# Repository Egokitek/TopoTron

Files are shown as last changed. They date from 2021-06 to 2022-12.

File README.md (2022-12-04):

# TopoTron

## Un display volumétrico de baja resolución 

### Concepto

**TopoTron** es un display volumétrico que utiliza LEDs direccionables **2812** para crear una matriz tridimensional. En este proyecto se exploran las posibilidades y capacidades que un dispositivo de este tipo ofrece para crear no solo topografías sino efectos visuales, animaciones etc.

Se asemeja en concepto a los conocidos **cubos LED**, pero en este caso el factor de forma es diferente, es un prisma de poca altura y bastante base. De este modo se pueden mostrar topografías mas fácilmente. También se presta atención a los difusores de luz de los LED . En un cubo LED normalmente no se emplean por lo que vemos una matriz de puntos luminosos que pueden crear efectos visuales pero no dan una buena sensación de volumen. En Topotron los difusores buscan un compromiso entre recrear un volumen y no entorpecer visualmente los LED que se encienden al frente con los que se encienden por detrás. Asi que el tipo de material del difusor, su tamaño y forma, y la distancia entre los mismos influyen en el efecto a conseguir.

En esta imagen de concepto vemos el objetivo ideal. Se ha realizado mediante el programa opensource **MagicaVoxel.**

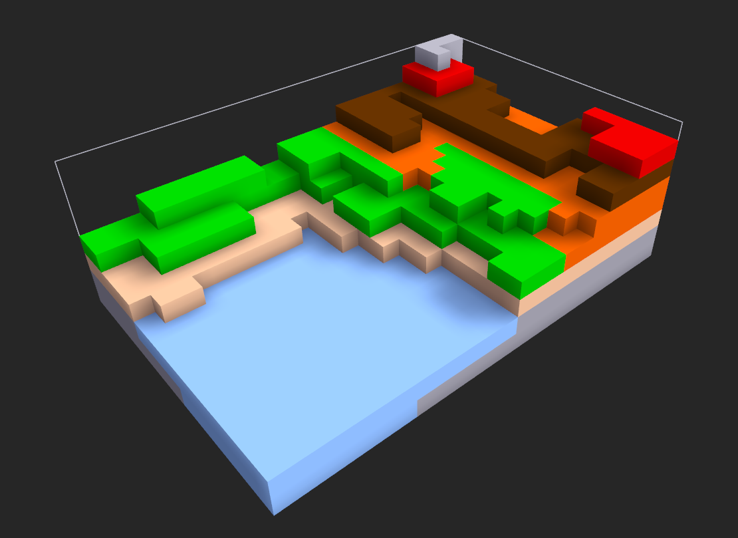
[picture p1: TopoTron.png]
TopoTron


### Características de los modelos y versiones:

- **Prototipo** desarrollado en verano 2021. **5x7x7 vóxeles** (245 LED totales). Construido sobre protoboards para facilitar el ensamblado y pruebas. Modelo usado como muestra en la campaña de crowdfunding. ESP8266 y firmware FASTLED modificado.

- **Versión 1 o mediana**. Desarrollado en primavera de 2022. **8x5x7 vóxeles** (280 LED totales). Completamente impreso en 3D con cableado y ensamblado interno. Procesador ESP8266 y firmware FastLED modificado.

- **Versión 2 o pequeña**. Desarrollado en verano de 2022. **5x5x10 vóxeles** (250 LED totales). Completamente impreso en 3D con cableado y ensamblado interno. Procesador ESP8266 y firmware WLED modificado. Versión modular que se puede ensamblar en unidades mayores.

La versión que se entregará como recompensa es la 2, que es por el momento la versión final y puede servir para crear modelos de tamaños diversos. Los vemos a continuación:

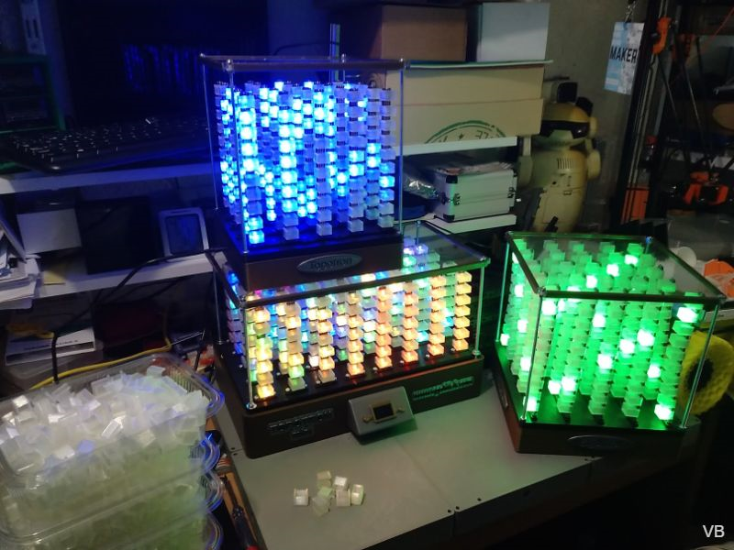
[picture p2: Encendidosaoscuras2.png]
Encendidos a oscuras


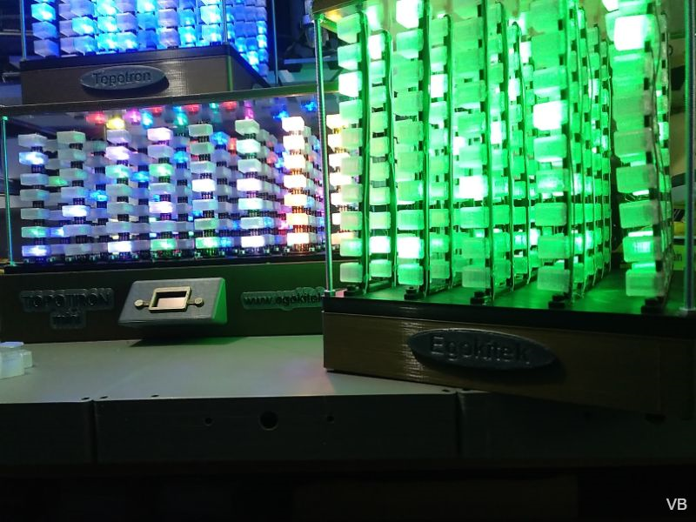
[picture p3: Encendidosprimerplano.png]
Encendidos primer plano


### Modelo grande (objetivo del proyecto): 

- **Versión L** en construcción, finalización en diciembre de 2022. Matriz mas grande con 15x10x10 vóxeles (1500 LED totales) o similar. Formada por 6 modelos V2 unidos entre si. Procesador ESP32 y firmware WLED modificado.

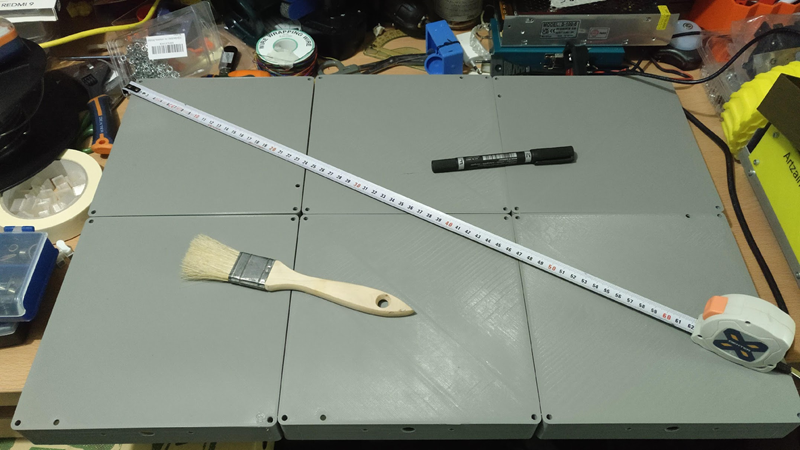
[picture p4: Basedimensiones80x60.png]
Modelo grande en construcción


### Lista de materiales (BOM):

El enlace está **[aquí](BOM.xlsx)** (en construcción):

### Crowdfunding y cofinanciadores:

Este proyecto se inicio como concepto y se prototipó en el marco del concurso internacional **Hackaday Prize** realizado en 2021. El enlace a ese proyecto (en inglés) está **[aquí](https://hackaday.io/project/180204-topotron).**

Se presentó a concurso y no quedó seleccionado, pero la idea me gustó y quise seguir trabajando con ella, con el fin de construir una unidad mas grande y ver así las posibilidades que ofrecía. Por ello me presenté a crowdfunding con la **Fundación Goteo** y a final de 2021 conseguí los fondos necesarios. 

Asi que este proyecto no hubiera sido posible sin el apoyo de las personas y colectivos que lo han cofinanciado. 

La ficha del proyecto en la **Plataforma Goteo** la tienes **[aquí](https://www.goteo.org/project/topotron).**

La lista de personas y colectivos que han contribuido a la financiación la tienes **[aquí](Cofinanciadores.md).**

### Futuro del proyecto:

En septiembre de 2022 he entrado a la empresa **Camp Tecnológico** dedicada entre otras cosas a la formación y el ocio tecnológico. En ella ampliaremos el catálogo de productos y servicios ya existente, al que se añadirá este proyecto.

Es un proyecto opensource con licencia GPL3.0, asi que eres libre de utilizarlo como quieras. Pero le seguiré dando continuidad desde el seno de la empresa en la que estoy actualmente.

## Creditos

**TopoTron** es un concepto desarrollado por **Victor Barahona** en **[Egokitek](https://www.egokitek.com/)**.

Se ha inspirado en los **cubos LED** y otros conceptos de **display volumétricos**.

En este proyecto estoy utilizando las librerías **FASTLED y WLED** con modificaciones.

## Licencia

**GPL3.0**

## Video demostrativo y mas imágenes:

Tienes mas imágenes en la carpeta de [**Galería.**](/Galería/README.md)

En este video teneis una muestra del desarrollo. Forma parte de una lista con varios videos mas. Os invito a ver el resto de contenidos. **[Topotron: desarrollo del proyecto](https://youtu.be/e-akGpGEZ80)**.

Renderizados hechos con **MagicaVoxel**

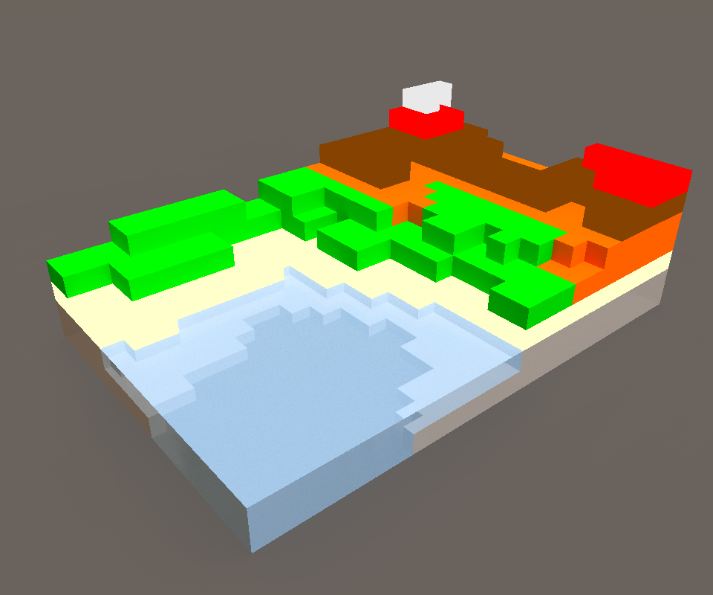
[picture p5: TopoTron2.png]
TopoTron2


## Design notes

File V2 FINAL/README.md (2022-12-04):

## Versión 2

### **Versión 2** (final) terminada en verano de 2022. 
 
Matriz con 5x5x10 vóxeles (250 LED totales). Completamente impresa en 3D con cableado y ensamblado interno. Procesador ESP8266 y firmware WLED modificado. Versión modular que se puede ensamblar en unidades mayores.

**Este es el aspecto del renderizado previo (realizado en Fusion360):**

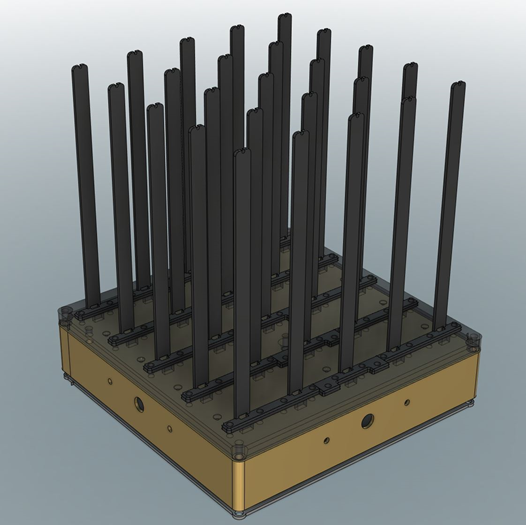
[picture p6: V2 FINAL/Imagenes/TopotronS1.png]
Renderizado en Fusion 360


**La unidad terminada se ve así.** En este caso está dada la vuelta, es algo posible debido a la placa superior protectora en metacrilato unida mediante barras roscadas de métrica 4.

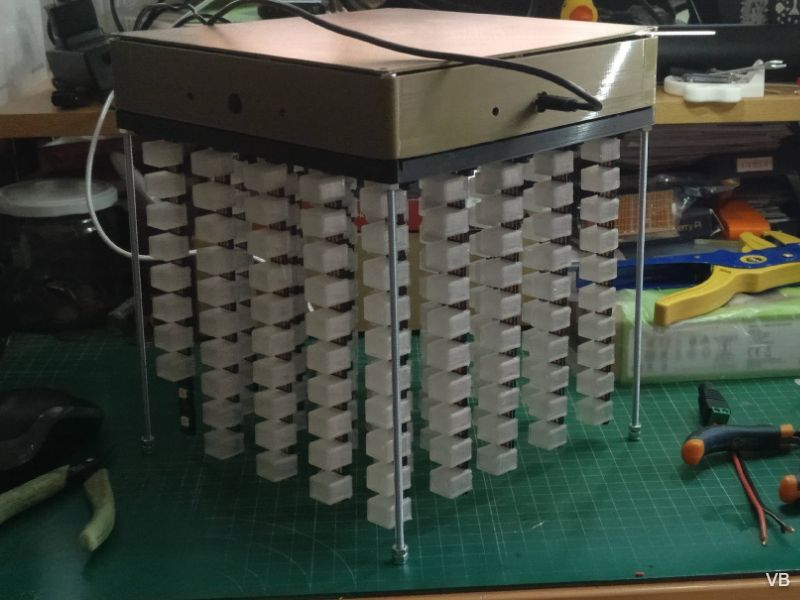
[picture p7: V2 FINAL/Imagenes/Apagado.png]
Topotron apagado


**Encendida se ve de esta manera:**

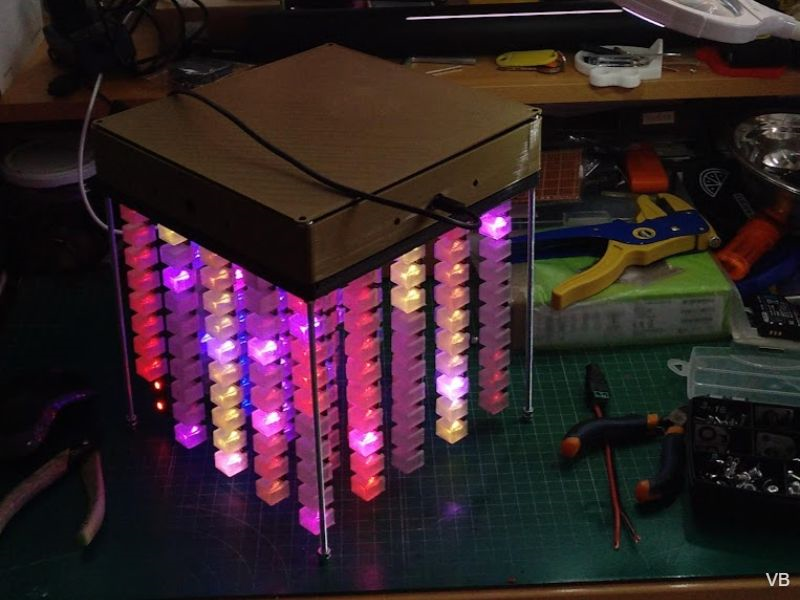
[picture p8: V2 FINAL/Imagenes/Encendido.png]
Topotron encendido


**Curiosamente basta con alimentar con una fuente USB de móviles al microcontrolador.** Este puede suministrar suficiente corriente para que los LED funcionen tal y como se ve en las fotos. Esto se debe a que el microcontrolador ESP8266 tiene una pataVin que puede servir de salida de la tension entrante por su puerto miniusb. Se limita por software la corriente máxima de salida a unos 500mA. Hay quien dice que se puede sacar hasta 1A o 1000mA) pero por precaución lo dejo en 500. No me han dado ningun problema los diferentes modelos que he construido hasta ahora para las recompensas.

### ¿Cómo se construye?

- Imprimimos 5 piezas de "Barra LED 5x10" , preferentemente en color negro, y sobre ellas pegamos tiras LED con una longitud de 10 LED. Antes de pegarlas les soldamos previamente un cable rojo para 5V, otro negro para GND y otro de cualquier color para Din (data input). todos estos cables han de tener una longitud de unos 3cm en 3 de las piezas. En una el de 5V será mas largo, de unos 8cm. Y en otra el GND tendrá 8cm. Esto se debe a las necesidades de conexionado posterior. Despues de soldar estos cables podemos pasarlos por un agujero en el soporte de "Barra LED 5x10", hay uno por cada tira. Y despues podemos pegarlas.

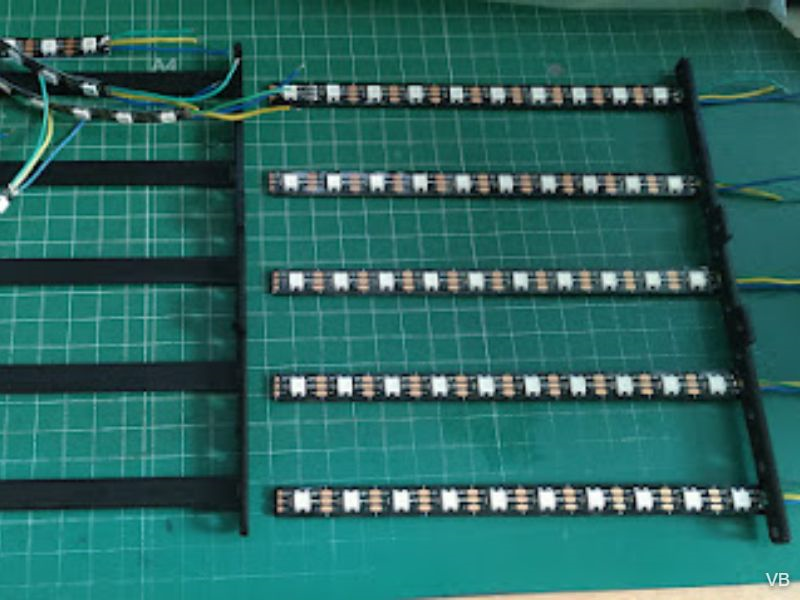
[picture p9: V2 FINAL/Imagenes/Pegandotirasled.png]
Pegando tiras LED


- Despues soldamos en la parte superior de cada tira, en su pin Dout, un cable largo de unos 20cm. En mi caso he empleado hilos de un antiguo bus IDE de ordenador, ya que son finos, flexibles y perfectamente válidos para esta tarea. Pero vale cualquier otro. Es conveniente que sea oscuro para que no destaque mucho sobre la pieza que es negra, ya que irá pegado en su parte posterior.

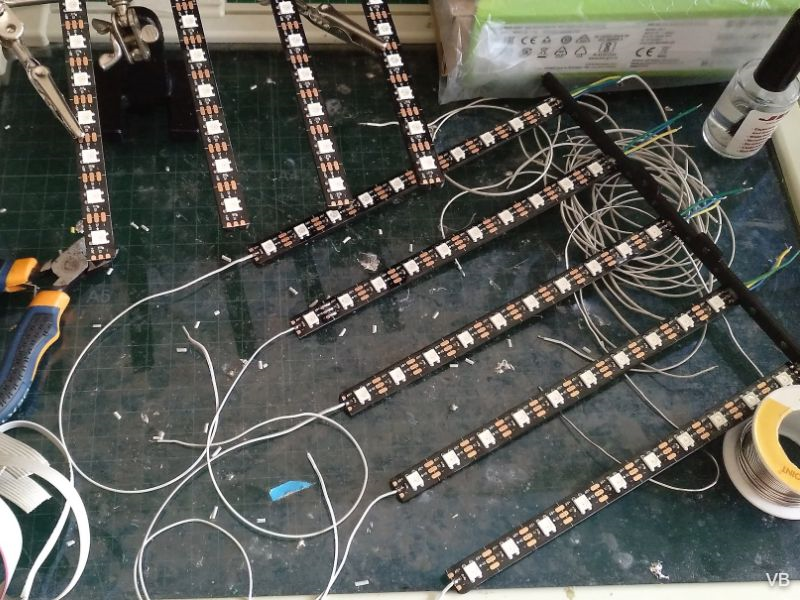
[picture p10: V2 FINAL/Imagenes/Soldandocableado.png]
Soldando cableado


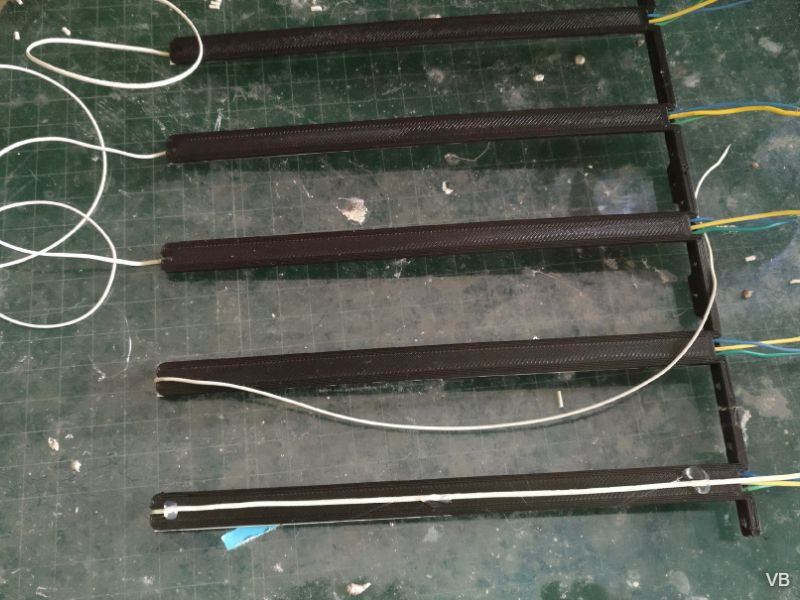
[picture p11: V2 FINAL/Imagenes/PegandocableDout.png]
Pegando cable Dout


- Después podemos pegar una a una todos los difusores sobre cada uno de los LED. Son 250 piezas de "celda QUAD v3". Las imprimimos en lotes de 25, 50 o como podamos, en PLA transparente o resina. En el caso de PLA con 3 perímetros y top/bottom de 3. Para pegarlas  el cianocrilato es una opción pero a mi me ha dado bastantes problemas. Recomiendo cola termofusible para esta tarea:

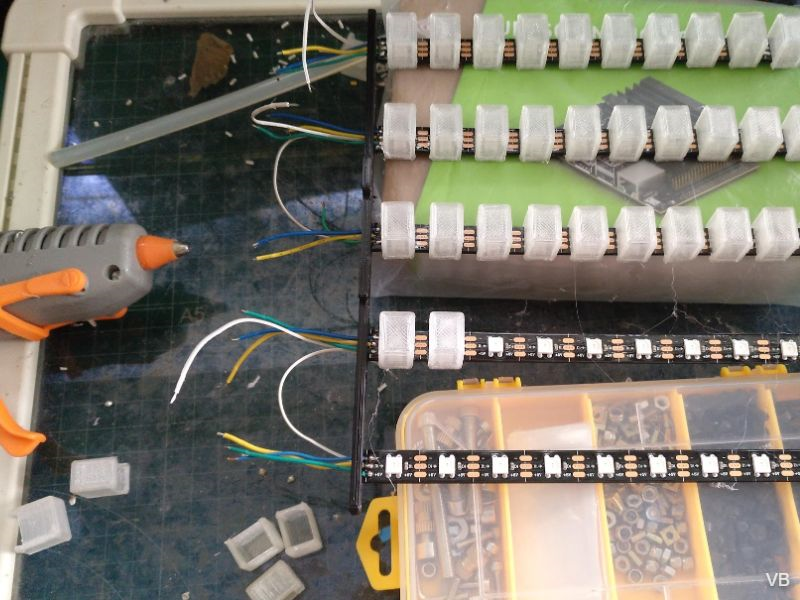
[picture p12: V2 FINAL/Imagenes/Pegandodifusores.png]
Pegando difusores


- Después de terminar las 5 piezas soporte de LED podemos unirlas a la pieza "Base tiras LED 5x5" (de esta sólo se imprime una). Los que tienen los colores rojo y negro de la misma longitud (sobre 3cm) están en las 3 posiciones centrales de la base. Mientras que los que tienen cable rojo (o negro) de unos 8cm se colocan en los extremos de la base. Primero debemos pasar el cableado (4 hilos por cada barra LED) a través del agujero correspondiente en la base, y cuando pasamos todos los hilos de las 5 barras de esa pieza se puede unir a la base con dos tornillos m3x10 a ambos lados, con la tuerca por la parte inferior. Apretamos bien y de ese modo todas las barras LED quedarán paralelas y verticales. Bien alineadas. Tenemos mas agujeros pasantes por si queremos poner mas tornillos m3x10 y reforzar la unión. Preferentemente usamos tornillos negros.

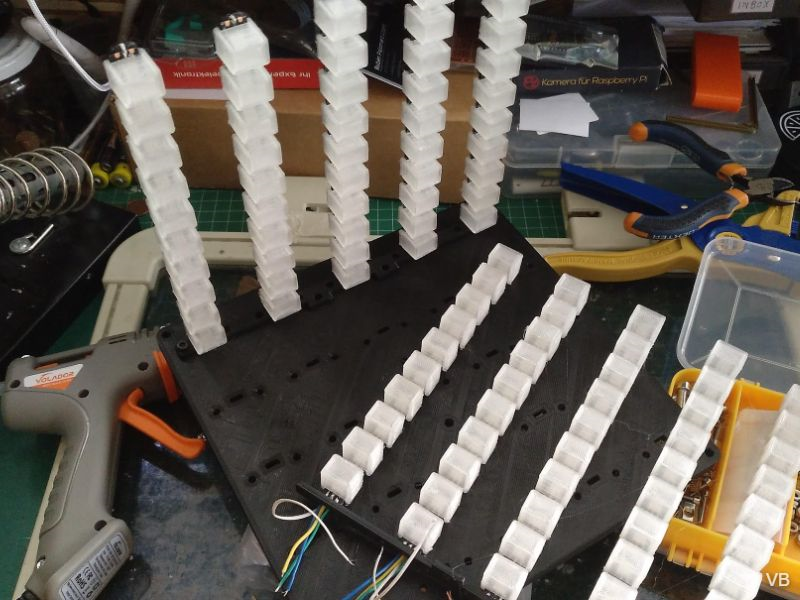
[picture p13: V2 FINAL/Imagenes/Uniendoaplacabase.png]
Uniendo a placa base


- Tras unir todas las piezas, si damos la vuelta al conjunto lo veremos de esta manera, con todos los cables pendientes de soldar. Atención, en la foto no se ven de color negro y rojo, solo es una recomendación para no confundirse, pero pueden emplearse otros colores como en este caso.

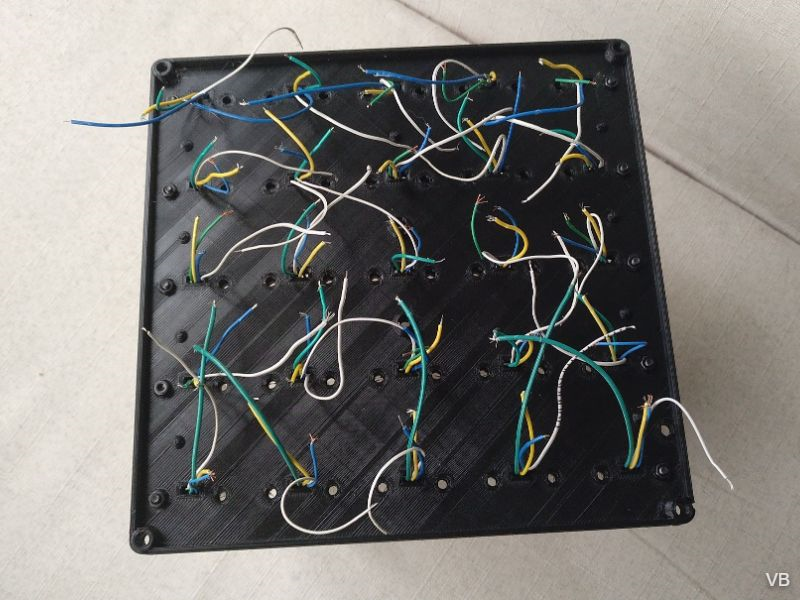
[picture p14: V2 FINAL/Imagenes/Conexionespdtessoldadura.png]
Conexiones pendientes de soldadura


- Cortamos 4 alambres de acero de aprox 1mm de diametro y 19cm de largo. Los pegamos con cinta de carrocero a la base, sobre unos pequeños promontorios en la pieza (hay 3 por cada alambre). Esto permitira hacer las soldaduras reduciendo el contacto directo con la pieza de PLA, que se puede dañar. Estos alambres serán 5V, GND, 5V, GND, en ese orden, de tal modo que todas las barras tendrán cerca alambres a los que ser soldados.

- Soldamos por tanto los cables rojos y negros a sus correspondiente alambres de 5V y GND. Los que tienen los colores rojo y negro de la misma longitud (sobre 3cm) están en las 3 posiciones centrales de la base. Mientras que los que tienen cable rojo (o negro) de unos 8cm se colocan en los extremos de la base, de tal forma que el cable largo va al alambre correspondiente que le queda a mayor distancia. Cuando terminemos de soldar todo podemos pegar los alambres con cola termofusible a los promontorios y retiramos la cinta de carrocero.

- Una vez de hecho lo anterior debemos unir cada cable Dout de una barra al cable Din de la siguiente, para que esten conectados en serie. El primer Din está libre porque es el que conectaremos al microcontrolador. El ultimo quedará sin conectar. Si miramos el conjunto de frente desde la parte superior empezaremos por la fila del fondo empezando a la izquierda. El primer Din a la izquierda es el que val controlador. De ahi conectamos su Dout a la Din de la siguiente columna LED, y asi sucesivamente a la derecha. Cuando llegamos a la ultima barra conectamos a la ultima en la derecha en la fila precedente, que es la que le queda contigua. Y en esa fila precedente conectamos de derecha a izquierda. La siguiente fila (la central) vamos de izquierda a derecha), la siguiente a izquierdas y por fin la quinta y ultima fila, la que está al frente a derechas. Esto es un poco lioso, lo ideal sería una foto o gráfico pero he sacado varias y no se aprecia bien. Adjunto una foto por si resulta aclaratorio. **IMPORTANTE: Poner un trozo de termoretractil a cada unión de datos para evitar cortocircuitos o comportamientos indeseados.**

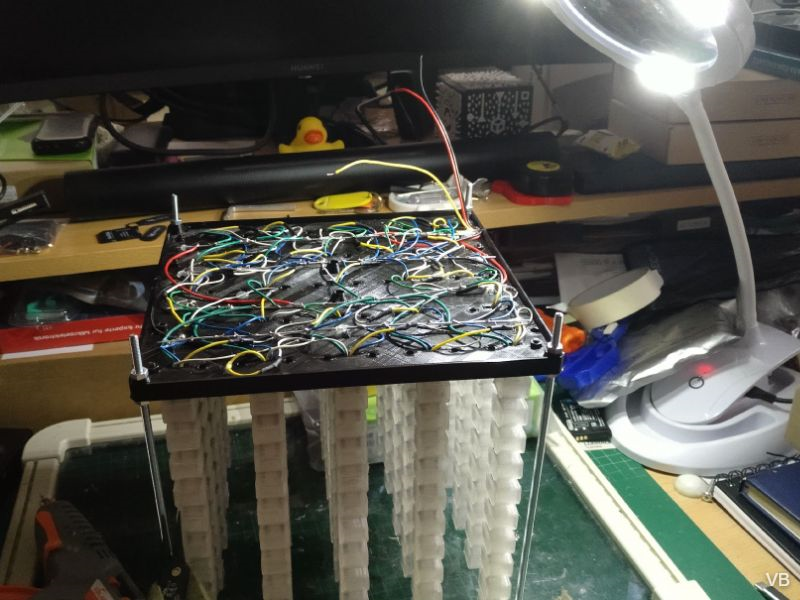
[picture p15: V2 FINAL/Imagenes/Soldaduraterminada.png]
Soldadura terminada


- Conectamos los dos alambres de 5V y los dos de GND entre si con un trozo de cable de suficiente sección.

- Conectamos un cable rojo a 5V y otro a GND, de suficiente sección, y de unos 15cm de longitud. De tal forma que esten alineados para poder salir por un agujero pasante a través de la pieza "base ppal" (ver mas adelante).

- **Conectamos el cable de Din de la primera barra LED a una resistencia de unos 470ohm** y despues a un cable de unos 15cm, este conectará al microcontrolador. Puede ponerse la resistencia al otro extremo, en el lado del MC. Este cable pasará también por el agujero pasante con los dos de 5V y GND.

- Hacemos una prueba de encendido (ver [**aquí**](/SW%20y%20configuración/README.md)) para asegurarnos de que todo funciona. Si es así, adelante al siguiente paso. Si no, toca revisar y reparar la/s soldaduras defectuosas, que es habitualmente la fuente de problemas.

- Si todo está bien podemos acomodar los cables para que abulten lo menos posible, incluso pegando en algunos puntos con cola termofusible. Quedará como en la foto.

- El controlador se coloca en la pieza "base ppal", sobre un espacio habilitado para ello, de tal forma que puerto micro usb quede apuntando el exterior por un egujero a medida. Le colocamos tornillos de m3x10 con tuerca a los agujeros al efecto en "base ppal". Puede que no entren los 4, pero basta con que entren dos en diagonal para que quede firmemente sujeto. El cableado se ha probado previamente en la prueba de encendido.

- Colocamos la "base de tiras led" en la pieza "base ppal" . Veremos 4 agujeros en las esquinas, son de métrica 4. Pasaremos 4 varillas roscadas de M4 y unos 25cm de largo c/u, a traves de la base de tiras led y la base ppal. Fijaremos ambas piezas con tuerca y contratuerca, de tal forma que por abajo sobresalga de la base ppal unos 2-3mm y queden base ppal y "base de tiras led" unidas. Debe haber una holgura de 1mm entre ambas. Es normal porque los promontorios de "base tiras led" están diseñado de esa manera. Es para que haya suficiente espacio para el cableado que se ha soldado.

- Conectamos Vin, GND y Din al cableado que llega desde la "base de tiras led" y fijamos este cableado para que no se mueva.

- Colocamos la pieza "tapa inferior", encaja a medida en las 4 varillas m4 y podemos unirla a la base. Cerramos con tuerca o mejor aun con tuerca autoblocante (nyloc).

- Pegamos con termofusible "Rotulo Topotron V2" en el frontal, "Rótulo Egokitek V2" en el lateral derecho y "Tapa decorativa" en la parte trasera. El lateral izquierdo se deja libre ya que es el punto de acceso al puerto microusb del microcontrolador.

- Cortamos una pieza de metacrilato de 20x20cm y la presentamos sobre las varillas roscadas. Marcamos los puntos y taladramos. La insertamos, de tal manera que tenemos tuerca y contratuerca para sujetarla. La tuerca superior puede ser una nyloc para evitar que se afloje con el tiempo.

- Por último pegamos en las aristas la pieza "arista 16cm", debemos sacar 4 copias. Estos es opcional pero sirve para cubrir la arista que puede ser afilada o tener un corte irregular. En la foto podemos ver el aspecto final que tiene. 
 
  ### A partir de ahora toca usar el equipo. 
  
  Para ello ve [**aquí**](/SW%20y%20configuración/README.md)

**Si quieres ver fotos del equipo encendido las tienes en la**  [**Galería:**](/Galería)

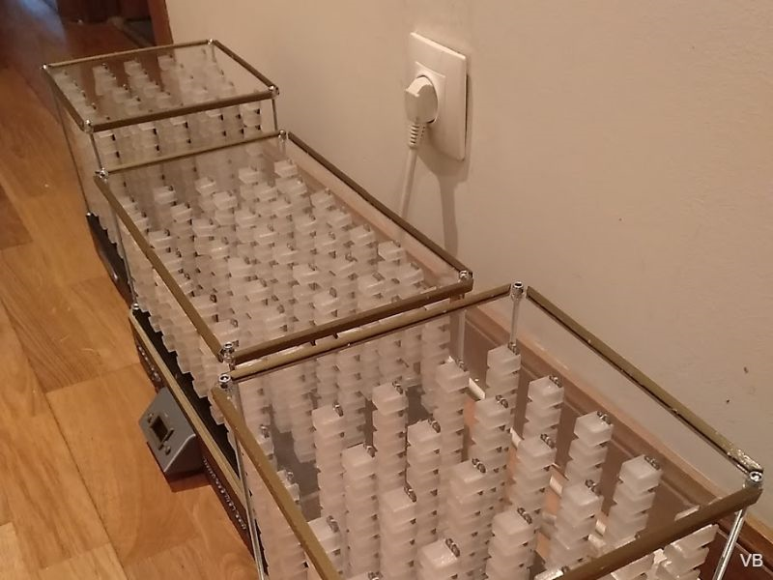
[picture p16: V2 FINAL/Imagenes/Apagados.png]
Apagados


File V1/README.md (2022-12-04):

## Versión 1 (M)

#### **Versión M** finalizada en primavera 2022. 
 
Matriz con 8x5x7 vóxeles (280 LED totales). Completamente impreso en 3D con cableado y ensamblado interno. Procesador ESP8266 y firmware FastLED modificado.

Inicialmente quería incluir un interfaz básico con display oled de 0,96 pulgadas y dos pulsadores. Llegó a estar operativo, pero al tiempo que lo terminaba encontré un proyecto que permitía manejar por wifi , se llama **WLED** y es el que finalmente he desplegado en todos los equipos. Reúne casi todos los requisitos que buscaba y con un excelente interfaz que puedes manejar desde movil, tableta u ordenador. 

**Este equipo** tiene un ancho de unos 32cm, lo que **requiere una impresora grande**. En mi caso utilicé una **Artillery X1**. El tema del tamaño me llevó a rediseñar el proyecto para que fuera modular y mas facil de imprimir. Por eso mismo no me detengo en su proceso constructivo, sino que adjunto algunas fotos. Si quieres hacer uno te recomiendo que vayas directamente a la versión dos que tienes [**aquí.**](/V2%20FINAL/README.md)

- En primer lugar, un renderizado hecho con **Fusion360:**
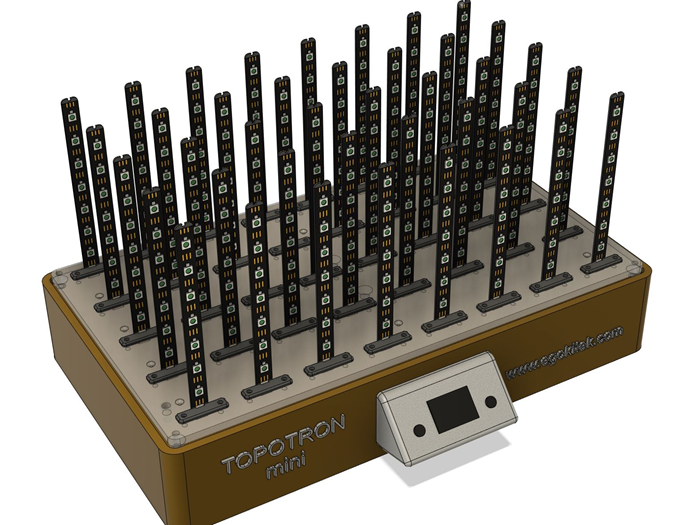
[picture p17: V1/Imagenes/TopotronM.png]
Topotron M renderizado


- La base se imprimió en color dorado ya que quería dar a este equipo un toque **steampunk:**
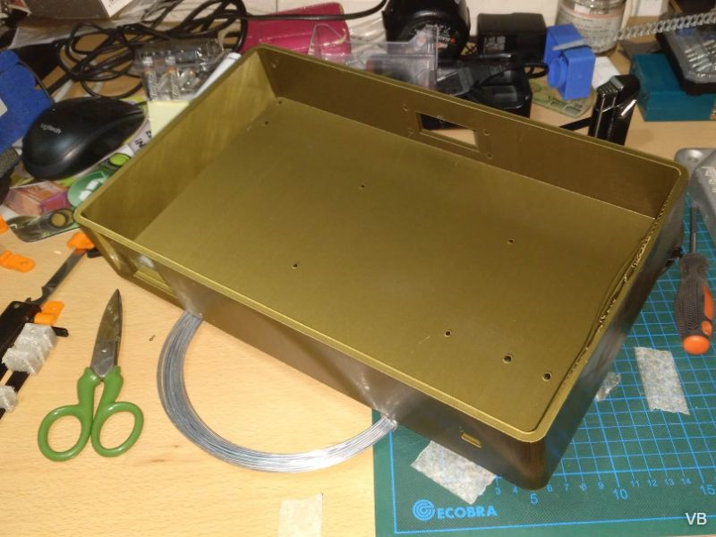
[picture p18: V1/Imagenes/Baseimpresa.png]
Base impresa


- Otra foto recién salida de la impresora, para apreciar la dificultad añadida por el tamaño y la cuestión de los soportes: en una pieza como esta añadiría mucho tiempo de impresión y material de soporte sobrante. Tomé el riesgo y pude imprimirla sin ellos.
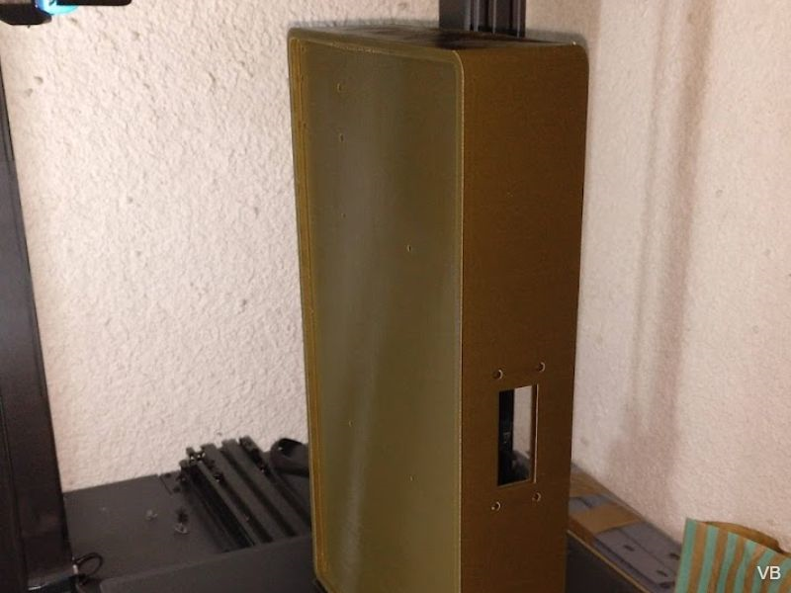
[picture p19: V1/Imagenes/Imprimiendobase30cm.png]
Imprimiendo base 30cm


- Aquí vemos el aspecto de la placa donde se montarán las barras LED y sus agujeros pasantes:
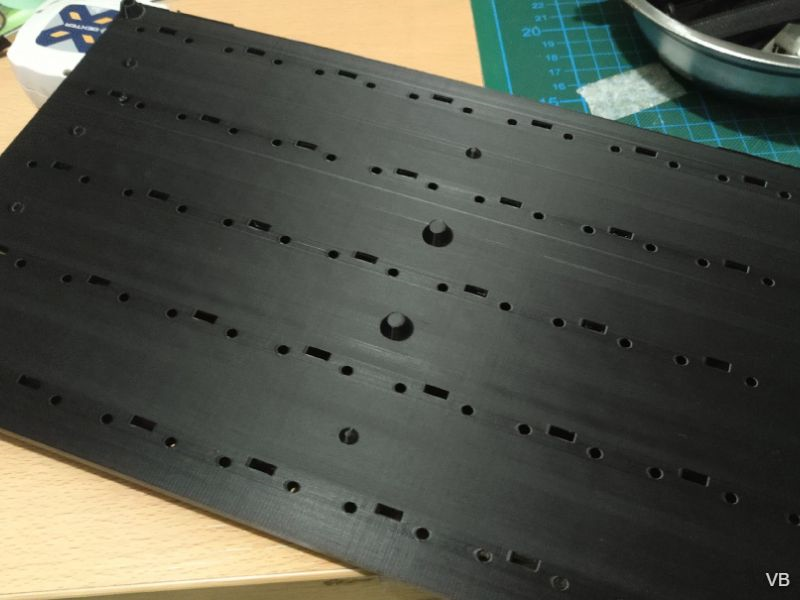
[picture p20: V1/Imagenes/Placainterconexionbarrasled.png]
Placa interconexión barras LED


- Y aquí el resultado final, a falta de la tapa superior en metacrilato. Mas fotos en la [**Galería**](/Galería/README.md):
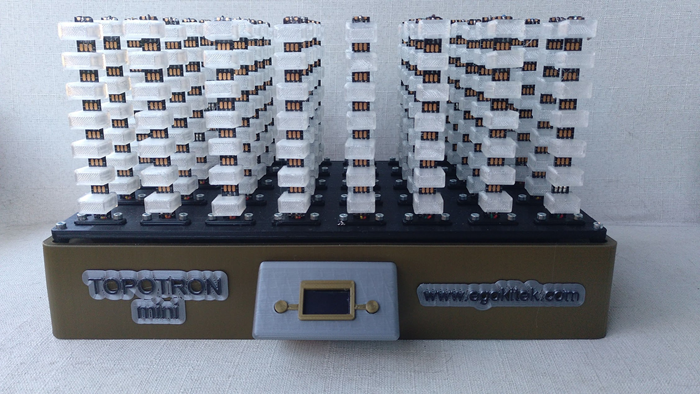
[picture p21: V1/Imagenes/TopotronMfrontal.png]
Topotron M vista frontal


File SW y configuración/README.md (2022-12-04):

## Software y configuración

### Requerimientos de Cableado:

- El cable **Din** de la primera barra LED debe conectarse a través de una resistencia de 470ohm al pin D4 del ESP8266.
- El  **GND** del ESP8266 y de los LED debe estar interconectado.
- El ESP8266 dispone de un pin llamado **Vin** que permite alimentar al ESP8266 sin necesidad de usar la toma USB. En ese caso es un conector de entrada. Pero cuando se conecta el USB este pin ofrece 5V de salida, siempre que no conectemos nada que supere una determinada intensidad. Según las fuentes leo que 500mA, otras que hasta 1000mA (1A). Asi que puede usarse para alimentar LED si no son muchos.
- A priori los LED deben tener un suministro propio de 5V ya que su amperaje puede superar con creces el que puede ofrecer el EP8266. Pero **el software WLED incluye una funcion muy interesante que permite limitar la corriente de salida**, asi que la ponemos a 500mA y nos garantizamos que la matriz LED puede funcionar. Esto nos permite conectar 5V a Vin y simplifica mucho la instalación.
 
La clave es saber si **es suficiente para que se desde Vin y con intensidad limitada los LED se pueden encender e iluminar bien. La respuesta es que si**, como podemos ver en la foto adjunta. Tanto es asi que podemos conectar a un banco de energía portátil y funcionará sin problema, haciendo el equipo completamente portable.

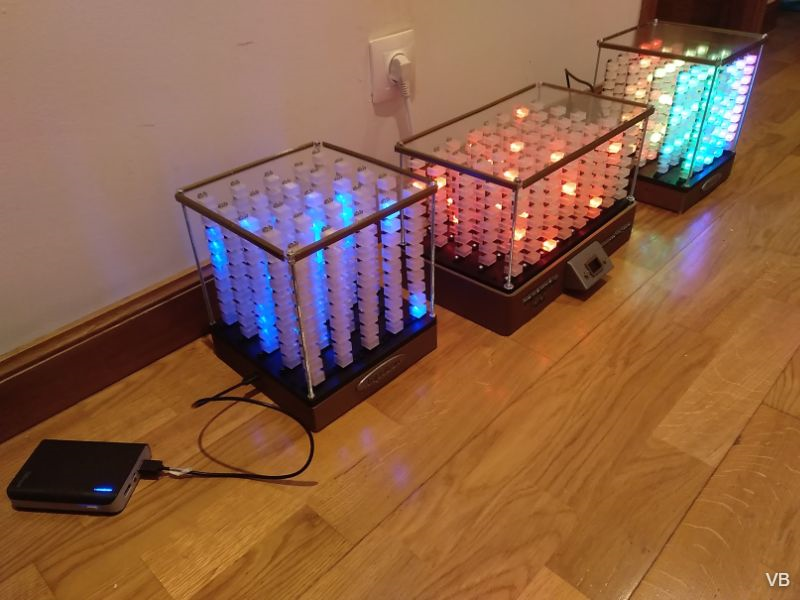
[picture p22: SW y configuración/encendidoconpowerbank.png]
Encendido con powerbank


### Carga del firmware

- Lo hacemos mediante el software WLED que podemos encontrar en su pagina oficial [**WLED**](https://kno.wled.ge/). Disponemos de tutoriales, comunidad y multitud de información que nos puede ayudar ajustar nuestro dispositivo.
- Dispone de varios procedimientos de instalación, el mejor es desde la web, lo tienes [**aquí.**](https://install.wled.me/) . Tendrás que tener el ESP8266 conectado por USB.
- Al conectar por cable desde el administrador de dispositivos (boton dcho en inicio, lo verás en el desplegable que se abre) verás que se activa un puerto COM, es en el que está conectado.
- En la web tenemos una opción para instalar, nos pedirá elegir el puerto, ponemos el que hemos visto activarse al conectar el ESP8266.
- Y ya casi está, la instalación es rápida y muy directa.
- OJO! Nos pedirá elegir una red Wifi para conectar, debemos poner la misma que usemos en el dispositivo desde el que conectamos. Normalmente será la doméstica. Pero yo me voy a eventos y para tener movilidad pongo mi móvil en modo punto de conexión, asi que aquí pongo el nombre de la red wifi que puedo asignar en mi movil. Si quieres usar en movilidad te recomiendo que hagas esto.

### Prueba de encendido

- Descargamos la app WLED para móvil, la tienes en la app store o google play.
- Nos aseguramos de que estamos en la misma red wifi.
- Al abrir la app pulsamos el boton **+** para buscar dispositivos compatibles.
- Nos avisará de que ha encontrado algo, salimos y veremos ahí el dispositivo con su num IP.
- Veremos que se encenderán en color ambar y muy suave unos cuantos LED, sobre 30. El SW está predeterminado asi , pero se puede cambiar. Para ello:
- Vamos a la pestaña de configuración y elegimos la opcion "LED preferences".
- Ahí dentro marcamos la casilla de limitacion de corriente, ponemos corriente máxima a 500mA, bajamos un poco y encontramos el num de LED que tenemos. Para Topotron V2 ponemos el valor 250. Subimos arriba y damos al botón "Save". Si todo ha ido bien veremos que se encienden todos los LED. A partir de ahi es jugar con la herramienta. Puedes seguir las instrucciones de la pagina web oficial y tambien hay videotutoriales en internet, casi todo en inglés.

### A partir de ahora?

Con el sw WLED se cumplen muchos de los requerimientos que buscaba en el proyecto, y se puede personalizar para llevarlo aun mas lejos. Pero hay algunas cosas que no son posibles y me gustaría que se puedan hacer. 

Por eso me propongo continuar con el proyecto y desarrollar un software propio, esto me llevara tiempo pq no es muy fuerte, pero estoy muy determinado asi que pasado un tiempo espero hacer actualizaciones al respecto.

Y si tienes alguna idea siempre puedes hacer algún **Pull Request**.

Seguimos!!

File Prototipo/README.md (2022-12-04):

## Versión prototipo

### **Prototipo** finalizado en verano 2021. 
 
5x7x7 vóxeles (245 LED totales). Construido sobre protoboards para facilitar el ensamblado y pruebas. Modelo usado como muestra en la campaña de crowdfunding. ESP8266 y firmware FASTLED modificado.

**Este equipo tuvo un uso efímero** y se utilizó en la campaña de captación de fondos del crowdfunding. Tras varios viajes quedo bastante maltrecho **asi que actualmente está desmontado.** Preveo reutilizar algunas de sus piezas para hacer un modelo pequeño y mas robusto, pero si deseas hacer uno vete directamente a la versión 2 que tienes [**aquí:**](/V2%20FINAL/README.md)

Adjunto algunas fotos del proceso de montaje así como algunas características:

- Creación de diversos tipos de difusores:
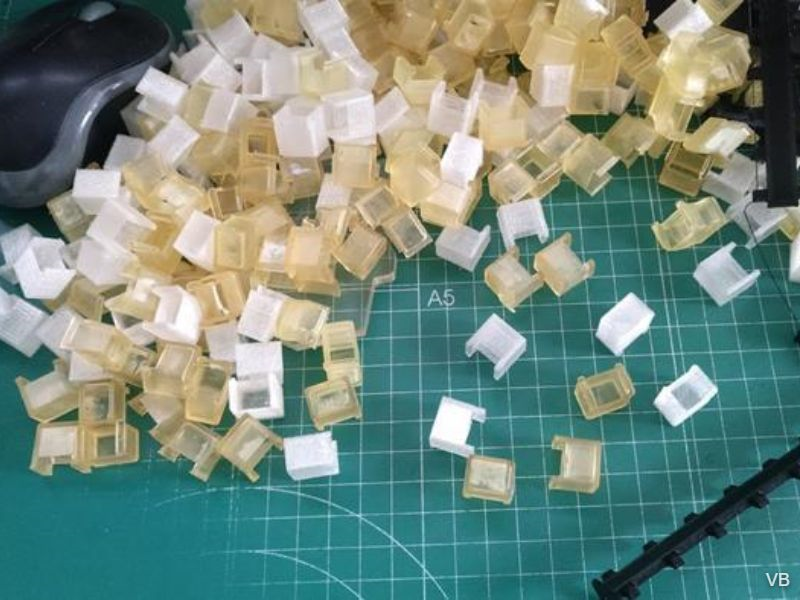
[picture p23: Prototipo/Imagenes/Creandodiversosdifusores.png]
Creando diversos tipos de difusores


- Difusores impresos en resina:
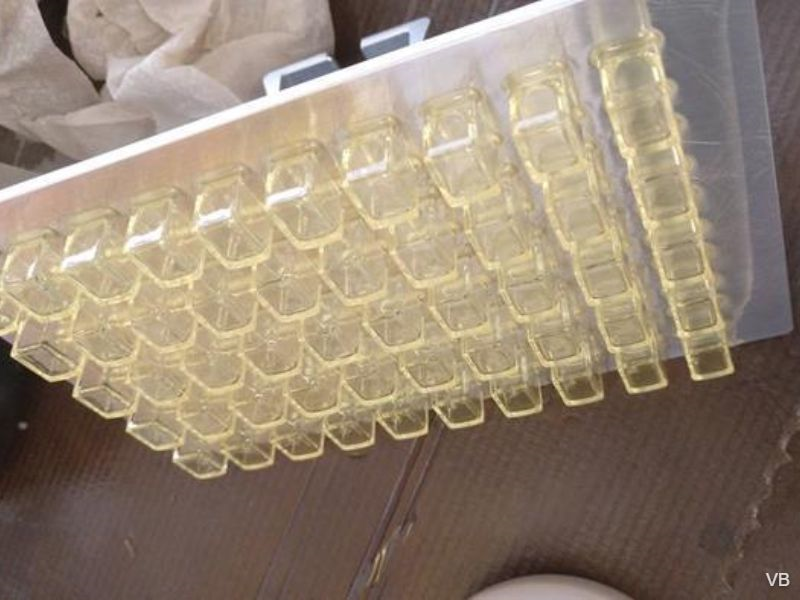
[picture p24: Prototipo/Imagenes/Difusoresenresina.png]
Difusores en resina


- Pruebas con diversos tipo de difusores:
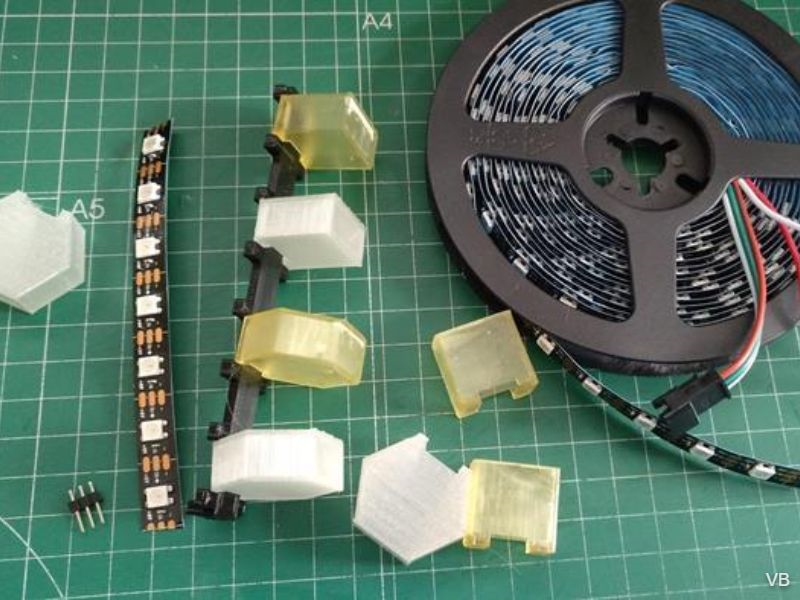
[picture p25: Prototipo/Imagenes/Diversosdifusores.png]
Diversos difusores


- Prueba de encendido de difusores para apreciar el efecto:
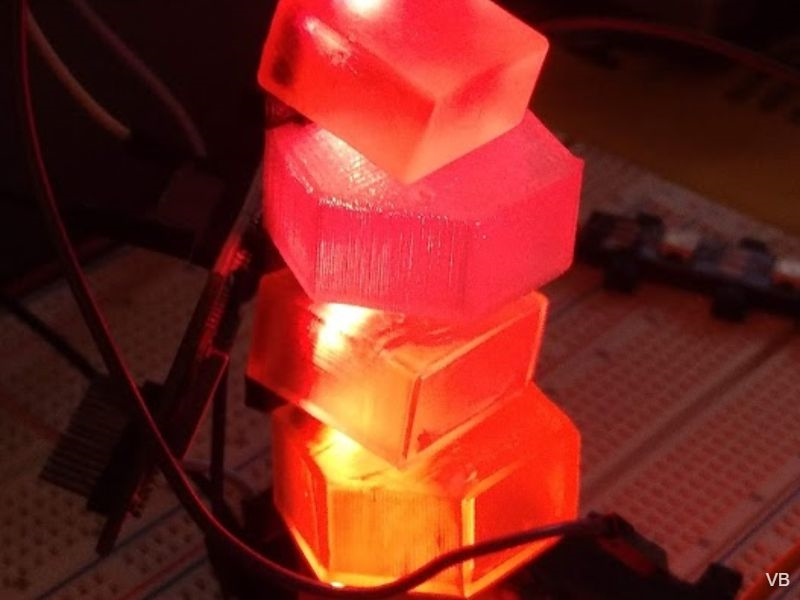
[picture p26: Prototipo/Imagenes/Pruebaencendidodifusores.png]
Prueba encendido difusores


- Ensamblado del prototipo en las protoboard:
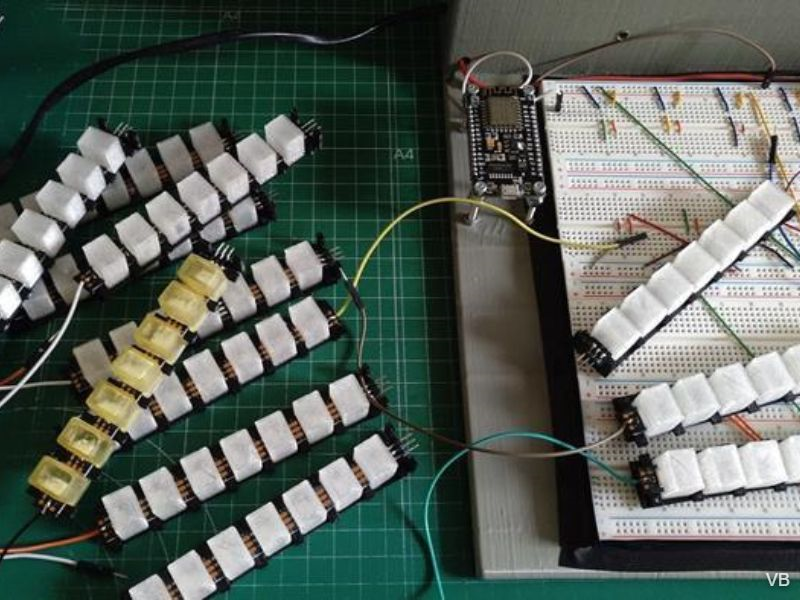
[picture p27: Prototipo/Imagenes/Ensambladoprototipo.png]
Ensamblado prototipo


- Equipo montado, aspecto final:
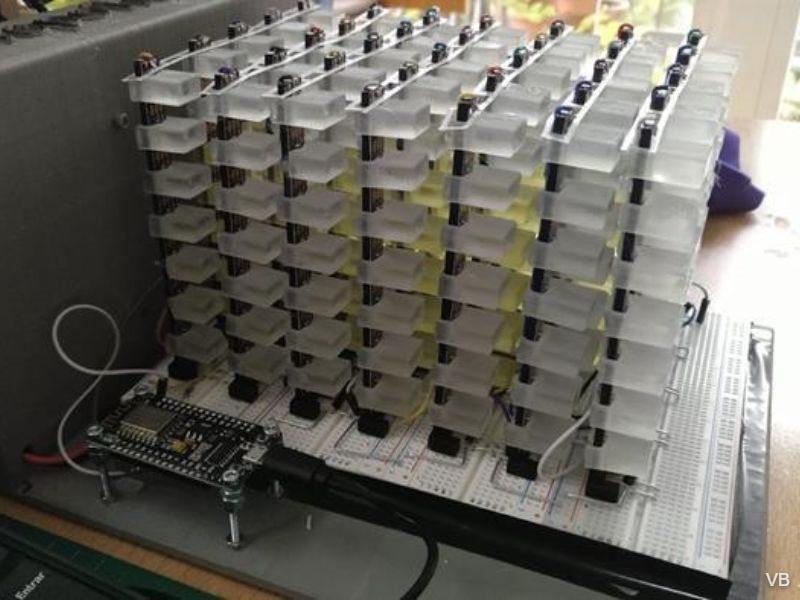
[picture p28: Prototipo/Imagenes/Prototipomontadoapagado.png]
Prototipo montado apagado


- Como vemos en las fotos, el ESP82266 está al lado izquierdo, unido a una pieza de chasis que aloja en su parte posterior una fuente de alimentación de 5V.
- Delante tenemos las protoboard, con interconexiones hechas mediante alambre de acero doblado a medida con pinzas. 
- Cada barra LED tiene 7 LED y se inserta individualmente en las protoboard. Todas las barras LED tienen conexion a 5V y GN, mas una entrada de datos Din y una salida Dout de tal forma qu están conectados en cascada. 
- El primer Din se conecta a la pata D4 en el ESP8266 con una resistencia limitadora de 470ohm (El cable blanco que se ve en la foto). 
- El ESP8266 debe estar conectado a la misma GND que el resto del equipo. 
- Como este modelo era el prototipo y estaba casi constantemente conectado al ordenador para reinstalar nuevo firmware se alimenta directamente desde el puerto microusb que vemos al frente.

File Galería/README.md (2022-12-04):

## GALERIA

#### Algunas fotos del equipo en funcionamiento:

- Varios Topotron apagados:
Apagados

- Encendidos con luz ambiente en un evento:
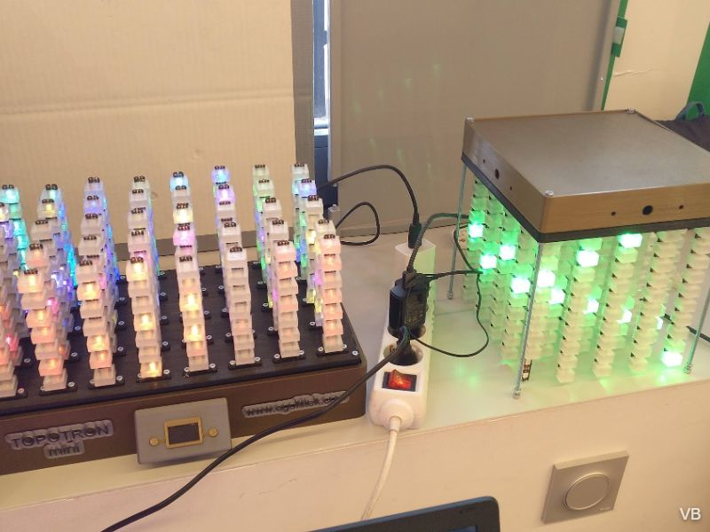
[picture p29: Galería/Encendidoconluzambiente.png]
Encendido con luz ambiente


- Encendidos con baja luz ambiente:
Encendidos con baja luz
Encendidos con baja luz 2

- Encendido con power bank (Si, gastan tan poco que pueden funcionar sin red):
Encendidos con power bank

- Encendidos a oscuras:
Encendidos a oscuras
Encendidos a oscuras 2

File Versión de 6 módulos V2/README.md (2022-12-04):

## Versión grande. 6 módulos V2 unidos

#### **Versión L** en construcción, finalización en diciembre 2022. 
 
Matriz mas grande con 15x10x10 vóxeles (1500 LED totales) o similar. Formada por 6 modelos V2 unidos entre si. Procesador ESP32 y firmware WLED modificado. Los datos se transmiten a través de 3 pines y no de uno, esto facilita la velocidad de refresco y gestión de los datos.

Renderizado hecho con **Fusion360**.
Vista renderizada

Los 6 módulos de 20x20 unidos forman una pieza de 60x40cm que presenta el siguiente aspecto:
Base 60x40

Por debajo la base se ve de esta manera. Contiene agujeros pasantes para union entre bloques y paso de cableado. Mas un punto donde colocar el MCU con salida de su puerto microUSB al exterior.
Vista inferior

Mas imágenes en la carpeta de [Imágenes](/Imagenes)

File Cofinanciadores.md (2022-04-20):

### Agradecimientos y mención de honor
### 20 | 04 | 2022

A continuación cito a todas las personas que habeis apoyado al desarrollo de este proyecto. Debo dar también las gracias a la **Diputación Foral de Gipuzkoa** por su apoyo a través del **programa META!** y a todas las personas que han donado y han pedido el anonimato.

Iré publicando noticias sobre su desarrollo en la cuenta GitHub de **[Egokitek](https://github.com/Egokitek/TopoTron/)** y asimismo aquí, en la pagina web de la **Fundación Goteo** que ha dado soporte para su desarrollo.

#### Agradecimiento con mención de honor para las siguientes personas:

- Carlos Vega Garcia
- Donosti en familia | Incitando a crecer
- Cesar Garcia Saez
- ander gisasola
- Oihane Pardo Pérez
- Luis Javier sierra diaz-perona
- Antuxuna
- Alvaro AHSTECNO
- M. Carlos Orts GarcÃ­a
- Aline
- Federico Coca Caba

#### Agradecimiento por su colaboración a las siguientes personas:

- Maria Salas
- Borja Alcalde

Seguiremos informando !!

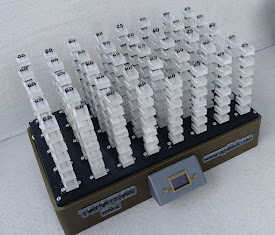
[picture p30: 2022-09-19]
V1/Imagenes/TopotronMlateral.png

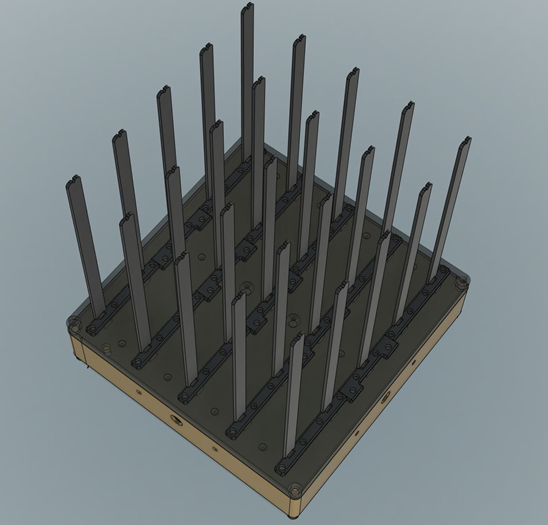
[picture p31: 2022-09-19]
V2 FINAL/Imagenes/TopotronS2.png

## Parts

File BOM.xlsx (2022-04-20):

TOPOTRON – LISTA DE MATERIALES
Item | Grupo | Cantidad | Coste | Total
TOTAL |  |  |  | 0

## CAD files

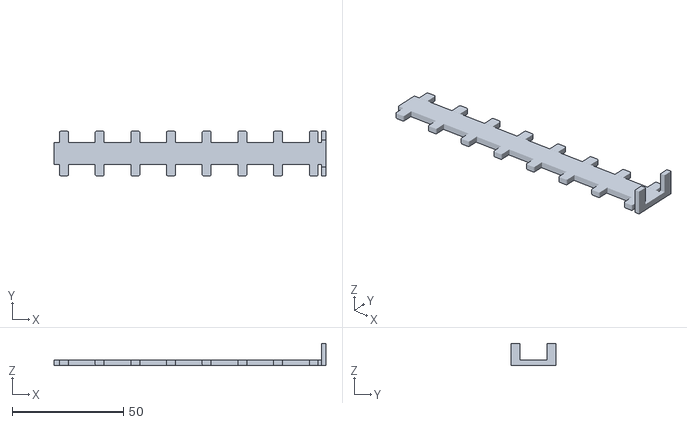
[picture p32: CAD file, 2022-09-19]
Prototipo/STL/Barra topotron.stl
122.0 x 20.0 x 10.0

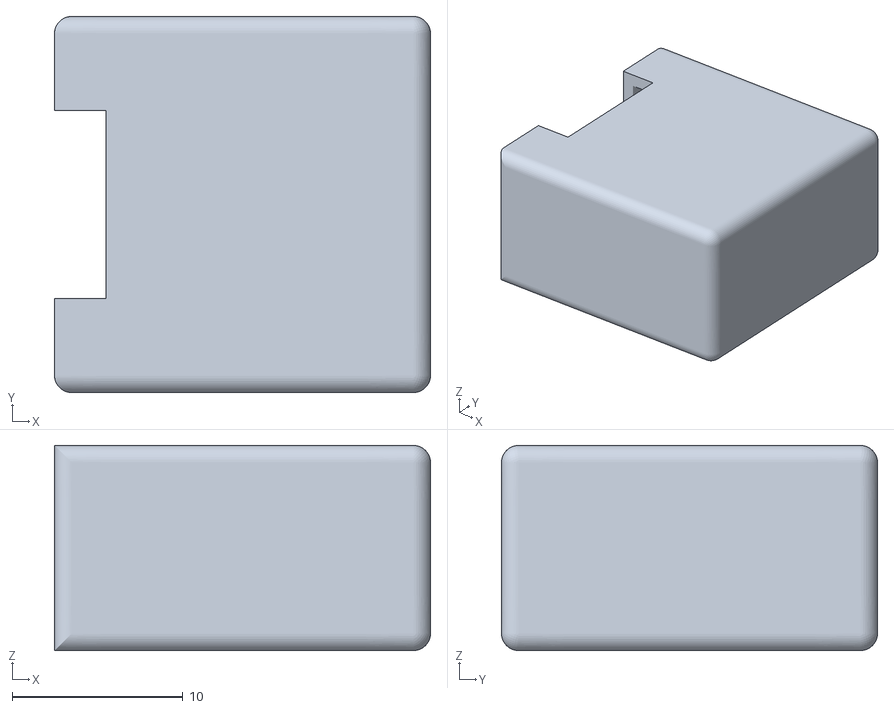
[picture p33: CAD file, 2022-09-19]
V1/STL/Celda CUAD.stl
22.0 x 22.0 x 12.0

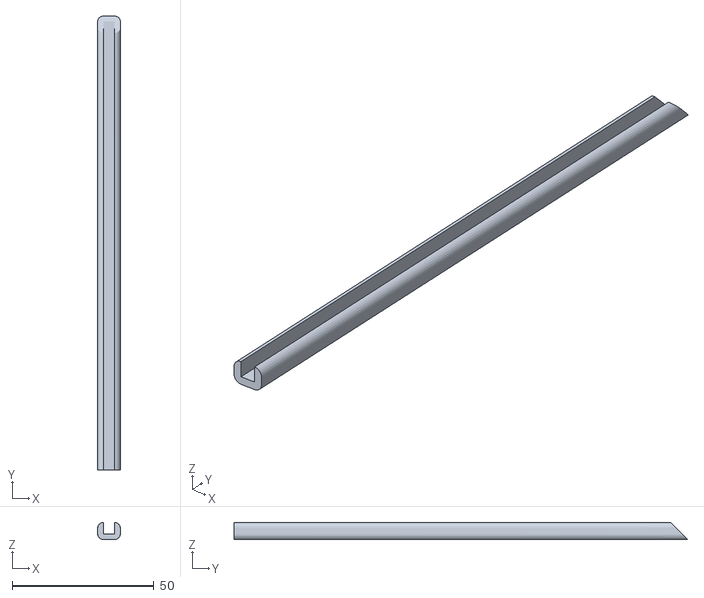
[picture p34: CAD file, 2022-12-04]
V2 FINAL/STL/Arista 16cm.stl
8.00 x 160.0 x 6.00

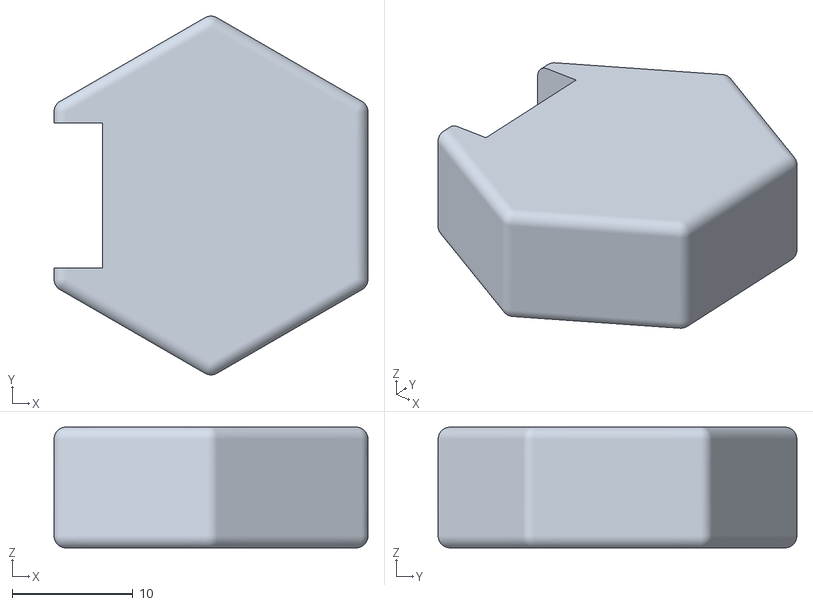
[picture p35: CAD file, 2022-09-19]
Prototipo/STL/Celda HEXmaciza.stl
26.0 x 29.7 x 10.0

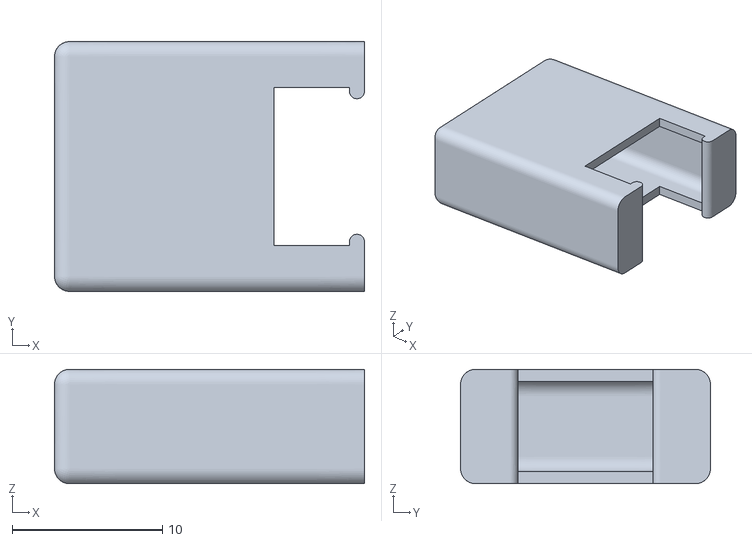
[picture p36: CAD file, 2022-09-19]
V1/STL/Celda CUAD V3.stl
20.6 x 16.6 x 7.60

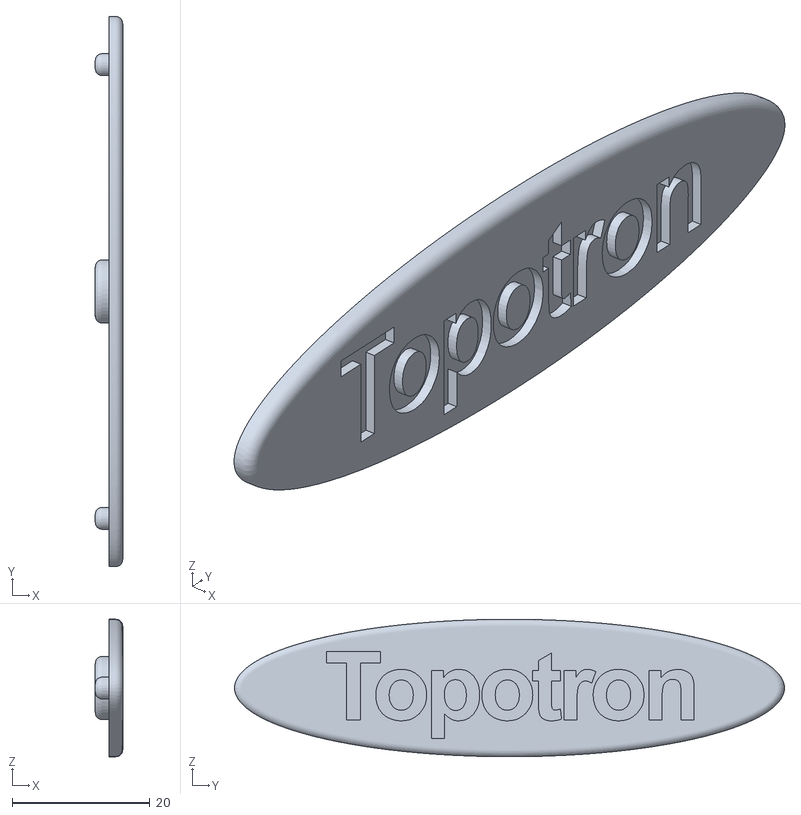
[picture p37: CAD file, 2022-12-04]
V2 FINAL/STL/Rotulo Topotron V2.stl
4.00 x 80.0 x 20.0

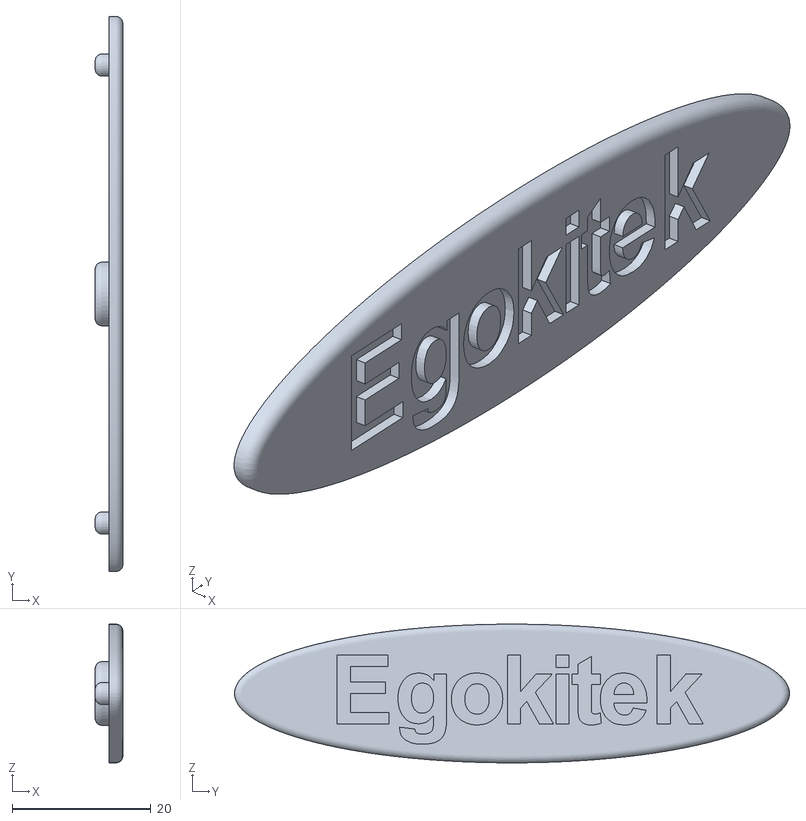
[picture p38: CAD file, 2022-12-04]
V2 FINAL/STL/Rotulo Egokitek V2.stl
4.00 x 80.0 x 20.0

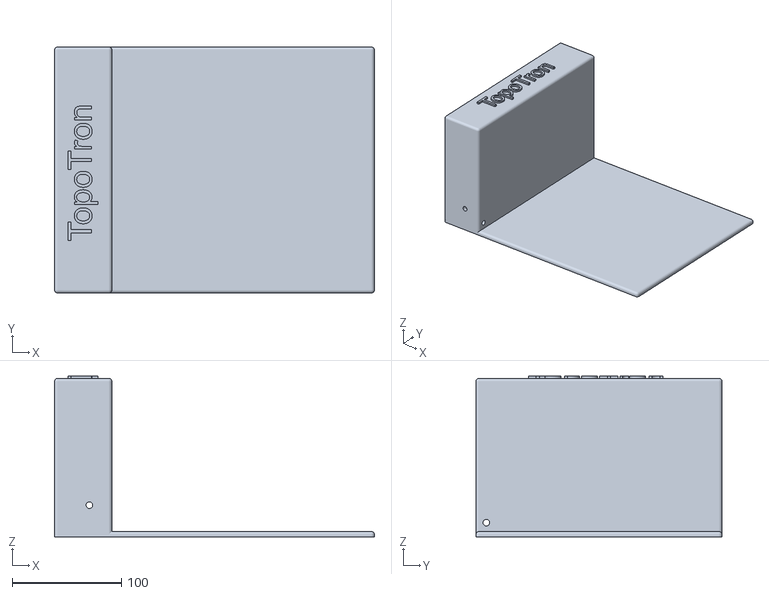
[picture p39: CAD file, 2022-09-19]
Prototipo/STL/Soporte Topotron.stl
292.5 x 225.0 x 147.0

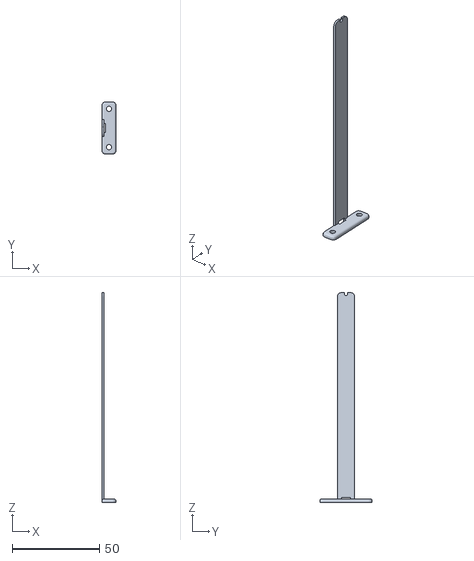
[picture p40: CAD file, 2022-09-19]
V1/STL/Barra LED S.stl
8.00 x 30.0 x 120.5

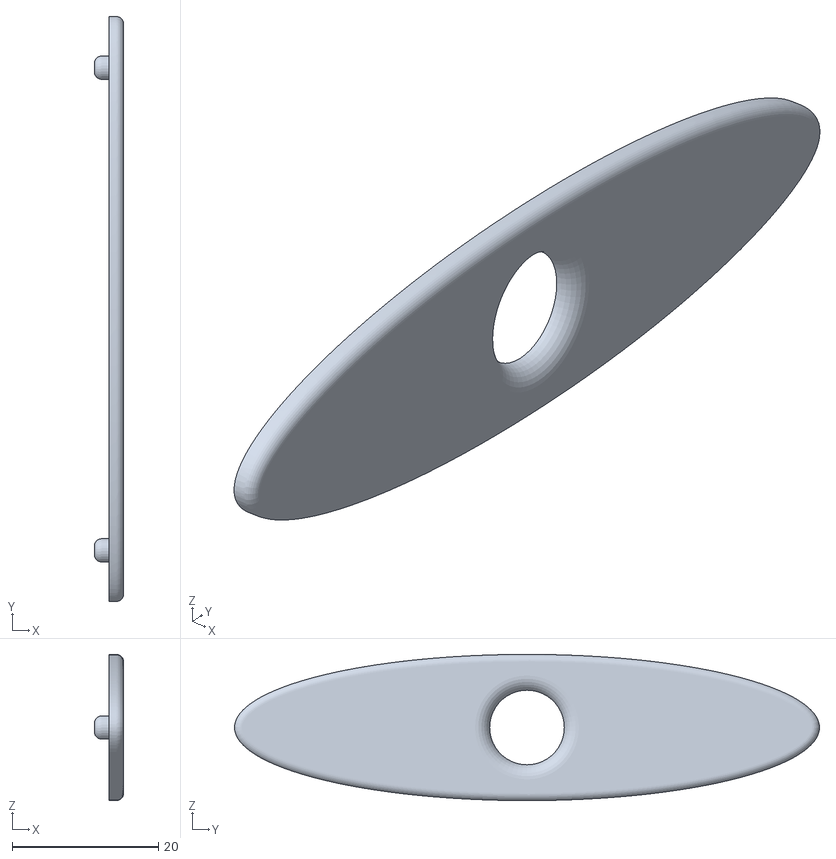
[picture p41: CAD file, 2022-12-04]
V2 FINAL/STL/Tapa decorativa.stl
4.00 x 80.0 x 20.0

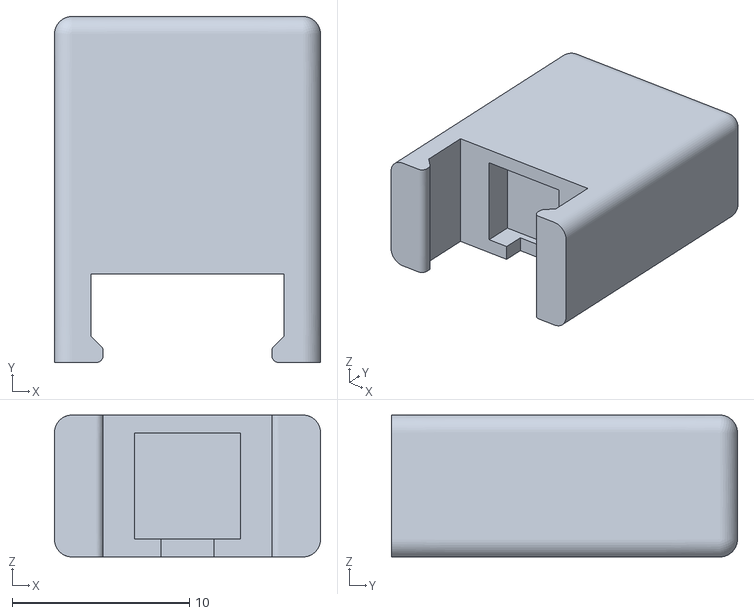
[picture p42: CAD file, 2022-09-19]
Prototipo/STL/Celda maciza CUAD V3.stl
15.0 x 19.5 x 8.00

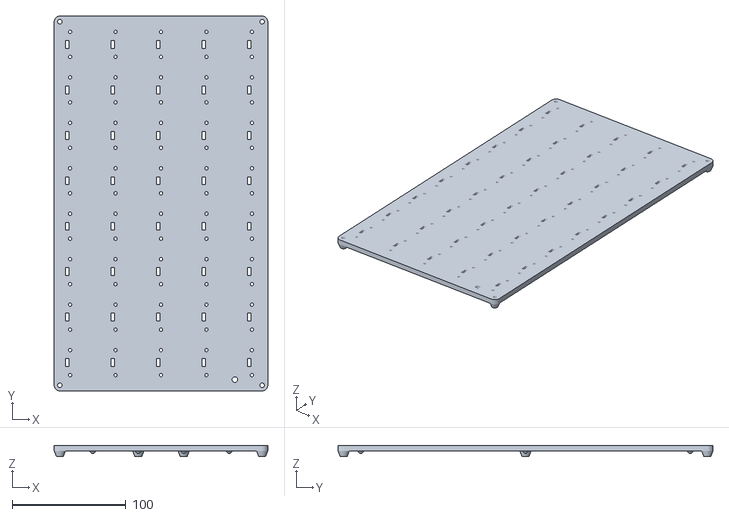
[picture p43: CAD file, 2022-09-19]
V1/STL/Base Barras LED S.stl
188.0 x 330.0 x 10.0

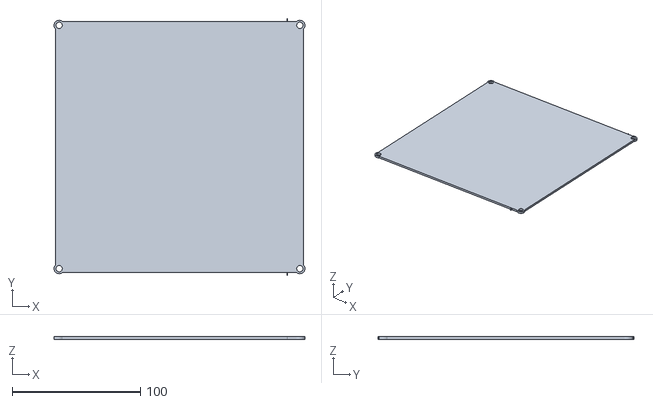
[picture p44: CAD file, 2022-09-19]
V2 FINAL/STL/Tapa inferior.stl
196.0 x 200.0 x 2.00

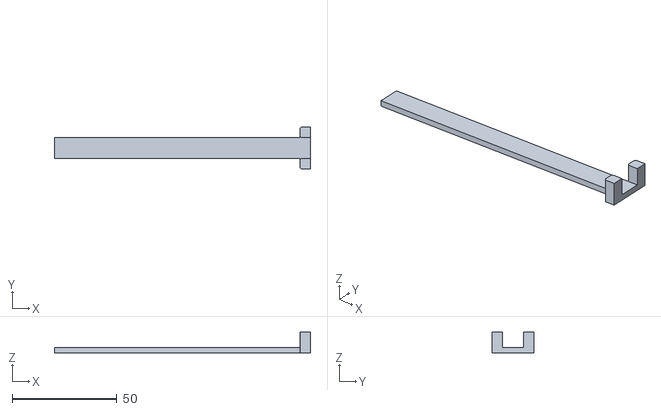
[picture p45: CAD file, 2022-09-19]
Prototipo/STL/V2 Barra topotron.stl
122.0 x 20.0 x 10.0

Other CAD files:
V1/STL/Rotulo Topotron mini.stl
V2 FINAL/STL/celda CUAD v3.stl
Prototipo/STL/Sop sup barras.stl
Prototipo/STL/Celda CUAD V2.stl
Prototipo/STL/Celda CUADmaciza.stl
Prototipo/STL/Celda HEX.stl
V1/STL/Celda CUAD V2.stl
V1/STL/Perimetro cuerpo.stl
V2 FINAL/STL/Barra LED 5x10.stl
V2 FINAL/STL/Base ppal.stl
V2 FINAL/STL/Base tiras Led 5x5.stl

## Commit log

2022-04-20 Actualizacion abril 2022
    Actualizacion Abril 2022
    [BOM.xlsx]
2022-09-19 Cambios 19 sep
    [Barra LED 5x10.stl, Barra LED S.stl, Barra topotron.stl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]
2022-12-04 Actualizacion 4dic22
    [Arista 16cm.stl, Rotulo Egokitek V2.stl, Rotulo Egokitek.stl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]
